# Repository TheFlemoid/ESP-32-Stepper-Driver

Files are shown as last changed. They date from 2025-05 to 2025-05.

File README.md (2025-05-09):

### ESP-WROOM-32 Based Stepper Motor Controller

PCB integrating an ESP-WROOM-32 microcontroller with two A4988/DRV8825 stepper motor drivers.

This is a four layer PCB that I originally designed this for an ESP-32 controlled, NEMA17 powered robot.  However it can also be useful for any other application requiring microcontroller control, stepper motors, and any form of SPI or I2C peripheral.

-----

Before connecting and driving the DRV8825, ensure that you set the current limit on both DRV8825/A4988 stepper drivers.

Features include:
 - 'Battery drive'.  Drive the board through a high voltage li-ion or LiPo battery, but enjoy three additional voltage rails:
    - 'Buck', aka the output from the onboard switching buck converter.
    - 5V rail through an onboard 5V LDO.
    - 3V3 rail through an onboard 3V3 LDO.
 - USB-C fast USB programming and UART.
    - USB-C programming for easy cable manipulation, but only fast USB (ie USB 2.0 speed specification) is supported.
    - 'Auto program' (utilizing USB to place the MCU in program mode) is supported.
 - Sleep, step, and direction pin connections for two DRV8825 stepper motor drivers.  Control speed, direction, and sleep on/off (useful for low current operation) for two steppers individually.
    - This was designed with the thought that each controller would be handled via the ESP-32 MCPWM peripheral, but it's entirely feasible to control them through software if desired.
 - Breakout for SPI.
 - Breakout for I2C.
    - Three pins each for both I2C SDA and SCL.
 - Voltage divider / voltmeter for 'battery' voltage.
 - Breakouts for ESP-32 GPIOs 13, 25, 26, and 36.
    - These were unused in the original design, but can be handy for extra outputs (eg another SPI CS pin) or inputs.
 - Pin headers for 1/8, 1/16, and 1/32nd microstepping.
    - Each stepper driver can be independently set for microstepping as required by your application.

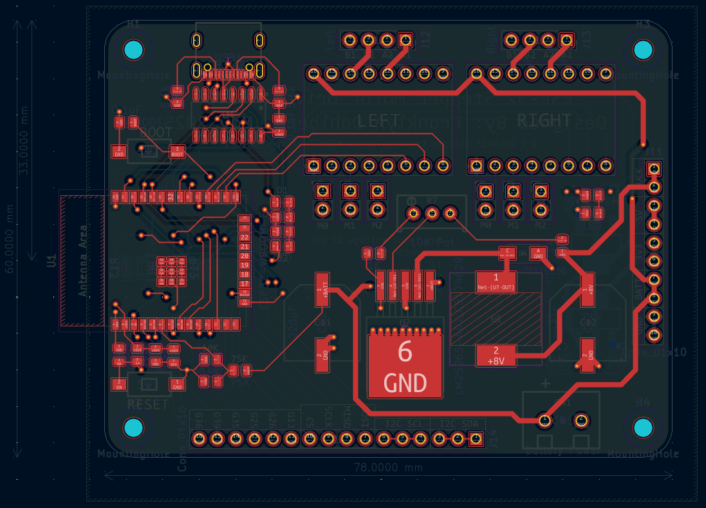
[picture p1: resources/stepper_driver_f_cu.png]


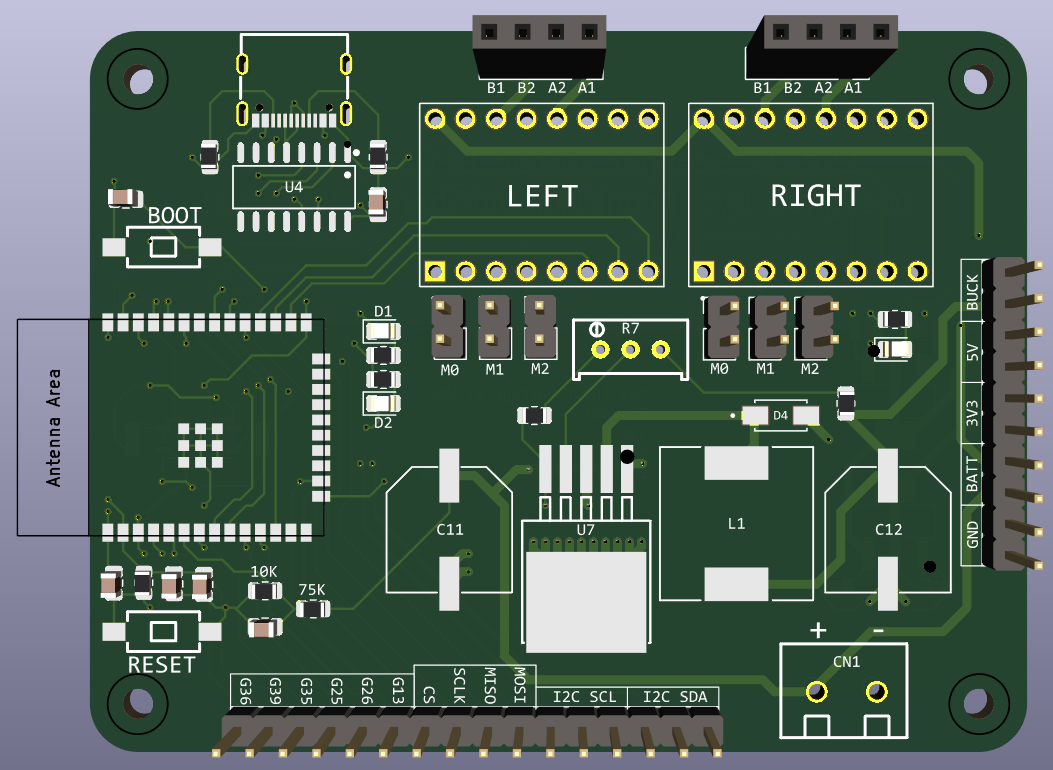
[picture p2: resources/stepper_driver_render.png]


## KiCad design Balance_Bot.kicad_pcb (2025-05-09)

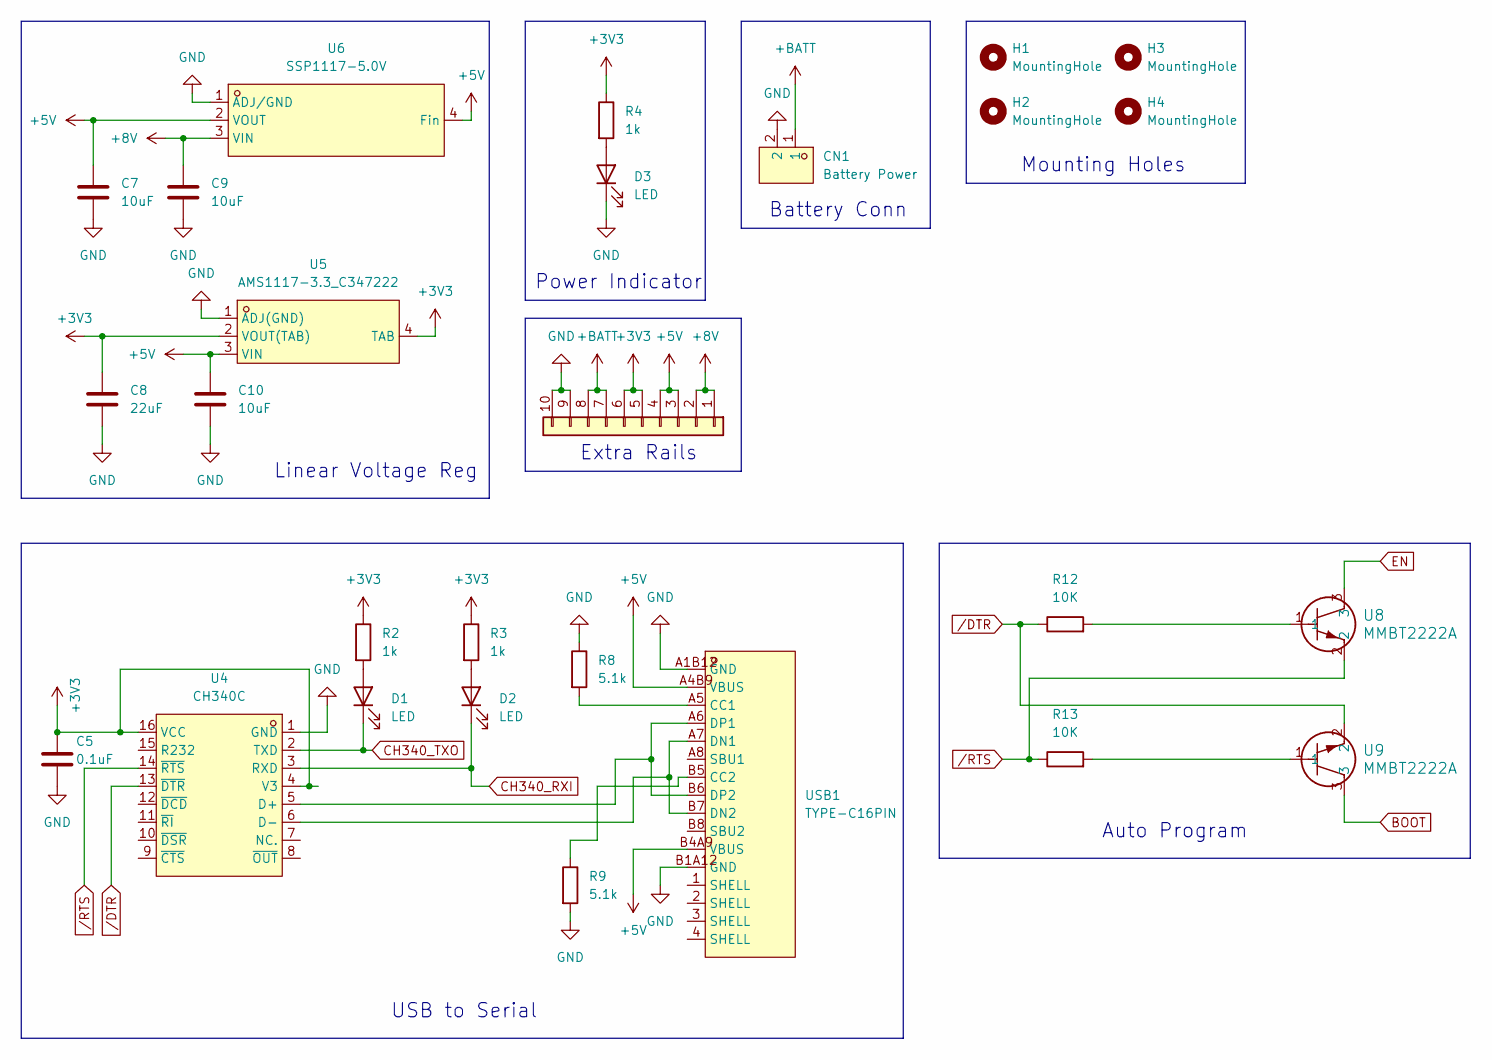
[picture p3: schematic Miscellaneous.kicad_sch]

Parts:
C5: 0.1uF; C_0805_2012Metric
C7, C9, C10: 10uF; C_0805_2012Metric
C8: 22uF; C_0805_2012Metric
CN1: Battery Power; CONN-TH_2P-P5.00_MX126-5.0-GN01-02P-CU-S-A; LCSC Part C5188434
D1, D2, D3: LED; LED_0805_2012Metric
H1, H2, H3, H4: MountingHole; MountingHole_2.5mm
J11: Conn_01x10; PinHeader_1x10_P2.54mm_Vertical
R2, R3, R4: 1k; R_0805_2012Metric
R8, R9: 5.1k; R_0805_2012Metric
R12, R13: 10K; R_0805_2012Metric
U4: CH340C; SOP-16_L10.0-W3.9-P1.27-LS6.0-BL; LCSC Part C84681
U5: AMS1117-3.3_C347222; SOT-223-4_L6.5-W3.5-P2.30-LS7.0-BR; LCSC Part C347222
U6: SSP1117-5.0V; SOT-223_L6.5-W3.5-P2.30-LS7.0-BR; LCSC Part C277893
U8, U9: MMBT2222A; SOT23_FAS
USB1: TYPE-C16PIN; USB-C-SMD_TYPE-C16PIN; LCSC Part C393939

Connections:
+3V3: C5.1, C8.1, J11.5, J11.6, R2.1, R3.1, R4.1, U4.4 (V3), U4.16 (VCC), U5.2 (VOUT(TAB)), U5.4 (TAB); also elsewhere on the board
+5V: C7.1, C10.1, J11.3, J11.4, U5.3 (VIN), U6.2 (VOUT), U6.4 (Fin), USB1.A4B9 (VBUS), USB1.B4A9 (VBUS)
+8V: C9.1, J11.1, J11.2, U6.3 (VIN); also elsewhere on the board
+BATT: CN1.1, J11.7, J11.8; also elsewhere on the board
BOOT: U9.3; also elsewhere on the board
CH340_RXI: D2.1 (K), U4.3 (RXD); also elsewhere on the board
CH340_TXO: D1.1 (K), U4.2 (TXD); also elsewhere on the board
EN: U8.3; also elsewhere on the board
GND: C5.2, C7.2, C8.2, C9.2, C10.2, CN1.2, D3.1 (K), J11.9, J11.10, R8.1, R9.2, U4.1 (GND), U5.1 (ADJ(GND)), U6.1 (ADJ/GND), USB1.A1B12 (GND), USB1.B1A12 (GND); also elsewhere on the board
unnamed: D1.2 (A), R2.2
unnamed: D2.2 (A), R3.2
unnamed: D3.2 (A), R4.2
unnamed: R12.2, U8.1
unnamed: R13.2, U9.1
unnamed: U4.5 (D+), USB1.A6 (DP1), USB1.B6 (DP2)
unnamed: U4.6 (D-), USB1.A7 (DN1), USB1.B7 (DN2)
unnamed: R8.2, USB1.A5 (CC1)
unnamed: R9.1, USB1.B5 (CC2)
/DTR: R12.1, U4.13 (~DTR), U9.2
/RTS: R13.1, U4.14 (~RTS), U8.2

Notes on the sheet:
Linear Voltage Reg
Mounting Holes
Extra Rails
USB to Serial
Power Indicator
Auto Program
Battery Conn

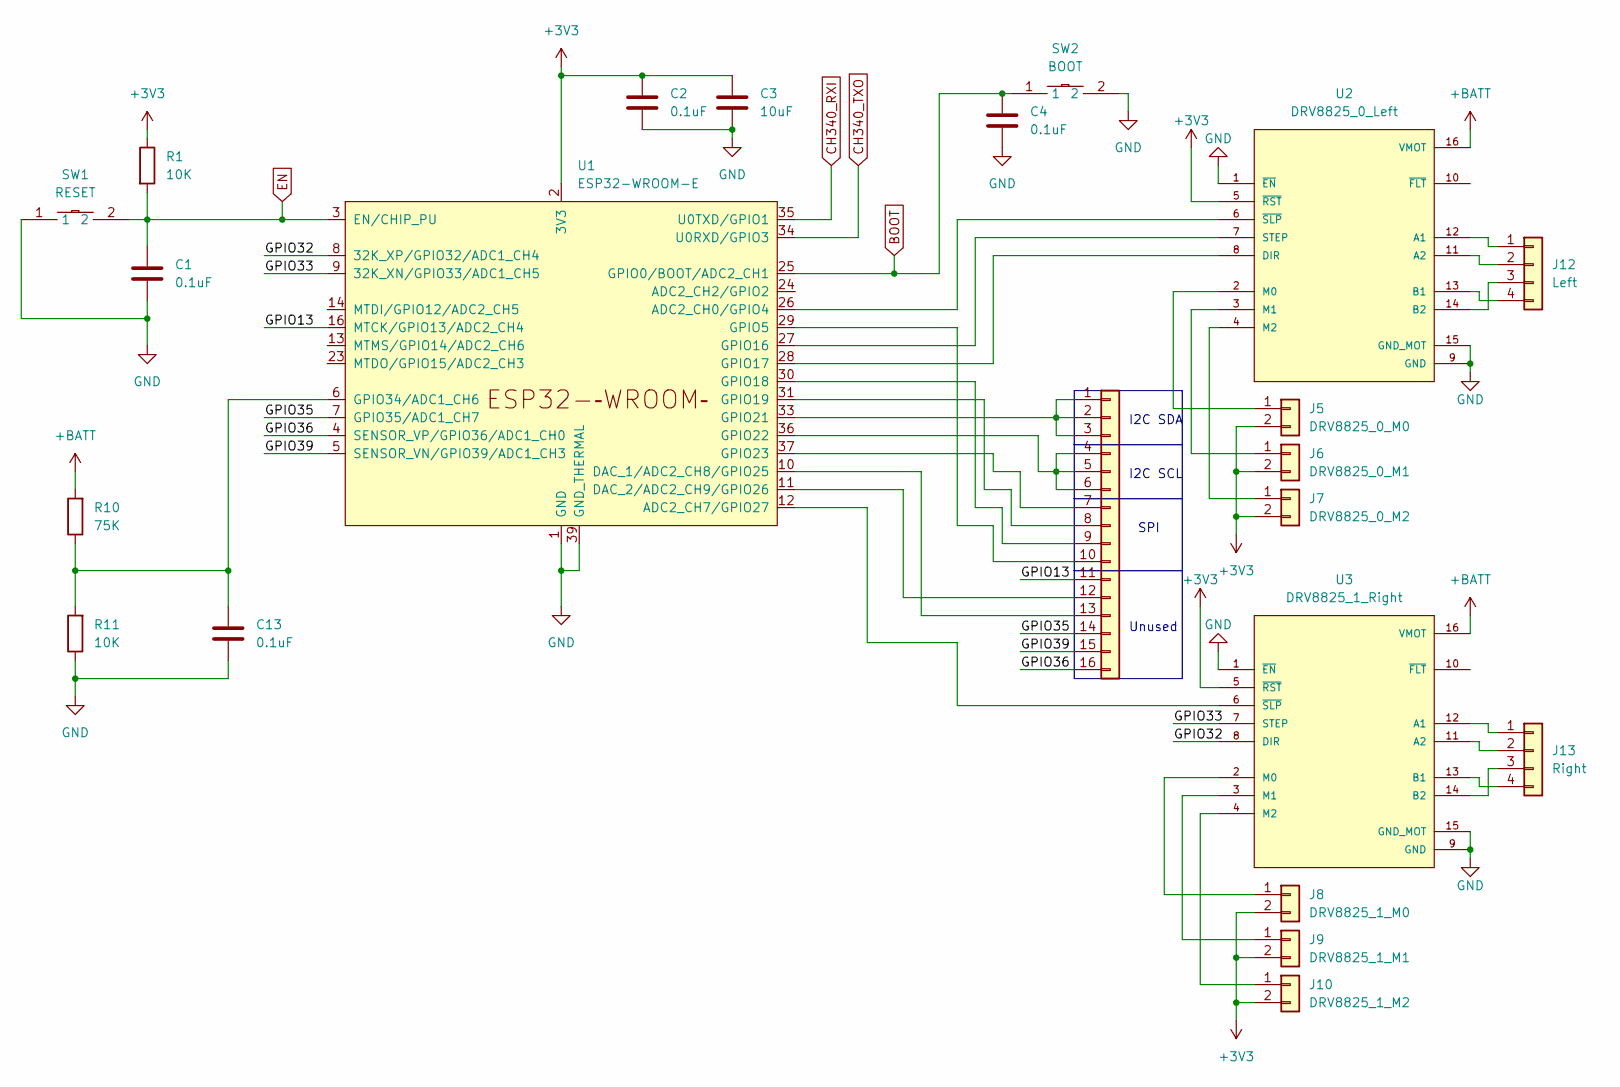
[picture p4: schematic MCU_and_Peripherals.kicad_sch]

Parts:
C1, C2, C4, C13: 0.1uF; C_0805_2012Metric
C3: 10uF; C_0805_2012Metric
J5: DRV8825_0_M0; PinHeader_1x02_P2.54mm_Vertical
J6: DRV8825_0_M1; PinHeader_1x02_P2.54mm_Vertical
J7: DRV8825_0_M2; PinHeader_1x02_P2.54mm_Vertical
J8: DRV8825_1_M0; PinHeader_1x02_P2.54mm_Vertical
J9: DRV8825_1_M1; PinHeader_1x02_P2.54mm_Vertical
J10: DRV8825_1_M2; PinHeader_1x02_P2.54mm_Vertical
J12: Left; PinSocket_1x04_P2.54mm_Vertical
J13: Right; PinSocket_1x04_P2.54mm_Vertical
J14: Conn_01x16; PinHeader_1x16_P2.54mm_Vertical
R1, R11: 10K; R_0805_2012Metric
R10: 75K; R_0805_2012Metric
SW1: RESET; SW-SMD_L6.0-W3.3-LS8.0; LCSC Part C318938
SW2: BOOT; SW-SMD_L6.0-W3.3-LS8.0; LCSC Part C318938
U1: ESP32-WROOM-E; ESP32-WROOM-32E
U2: DRV8825_0_Left; IC_DRV8825_STEPPER_MOTOR_DRIVER_CARRIER
U3: DRV8825_1_Right; IC_DRV8825_STEPPER_MOTOR_DRIVER_CARRIER

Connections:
+3V3: C2.1, C3.1, J5.2, J6.2, J7.2, J8.2, J9.2, J10.2, R1.1, U1.2 (3V3), U2.5 (~RST), U3.5 (~RST); also elsewhere on the board
+BATT: R10.2, U2.16 (VMOT), U3.16 (VMOT); also elsewhere on the board
/MCU_and_Peripherals/GPIO13: J14.11, U1.16 (MTCK/GPIO13/ADC2_CH4)
/MCU_and_Peripherals/GPIO32: U1.8 (32K_XP/GPIO32/ADC1_CH4), U3.8 (DIR)
/MCU_and_Peripherals/GPIO33: U1.9 (32K_XN/GPIO33/ADC1_CH5), U3.7 (STEP)
/MCU_and_Peripherals/GPIO35: J14.14, U1.7 (GPIO35/ADC1_CH7)
/MCU_and_Peripherals/GPIO36: J14.16, U1.4 (SENSOR_VP/GPIO36/ADC1_CH0)
/MCU_and_Peripherals/GPIO39: J14.15, U1.5 (SENSOR_VN/GPIO39/ADC1_CH3)
BOOT: C4.1, SW2.1, U1.25 (GPIO0/BOOT/ADC2_CH1); also elsewhere on the board
CH340_RXI: U1.35 (U0TXD/GPIO1); also elsewhere on the board
CH340_TXO: U1.34 (U0RXD/GPIO3); also elsewhere on the board
EN: C1.1, R1.2, SW1.2, U1.3 (EN/CHIP_PU); also elsewhere on the board
GND: C1.2, C2.2, C3.2, C4.2, C13.2, R11.1, SW1.1, SW2.2, U1.1 (GND), U1.15 (GND), U1.38 (GND), U1.39 (GND_THERMAL), U2.1 (~EN), U2.9 (GND), U2.15 (GND_MOT), U3.1 (~EN), U3.9 (GND), U3.15 (GND_MOT); also elsewhere on the board
unnamed: J5.1, U2.2 (M0)
unnamed: J6.1, U2.3 (M1)
unnamed: J7.1, U2.4 (M2)
unnamed: J8.1, U3.2 (M0)
unnamed: J9.1, U3.3 (M1)
unnamed: J10.1, U3.4 (M2)
unnamed: J12.1, U2.12 (A1)
unnamed: J12.2, U2.11 (A2)
unnamed: J12.3, U2.14 (B2)
unnamed: J12.4, U2.13 (B1)
unnamed: J13.1, U3.12 (A1)
unnamed: J13.2, U3.11 (A2)
unnamed: J13.3, U3.14 (B2)
unnamed: J13.4, U3.13 (B1)
unnamed: J14.1, J14.2, J14.3, U1.33 (GPIO21)
unnamed: J14.4, J14.5, J14.6, U1.36 (GPIO22)
unnamed: J14.7, U1.37 (GPIO23)
unnamed: J14.8, U1.31 (GPIO19)
unnamed: J14.9, U1.30 (GPIO18)
unnamed: J14.10, U1.29 (GPIO5)
unnamed: J14.12, U1.11 (DAC_2/ADC2_CH9/GPIO26)
unnamed: J14.13, U1.10 (DAC_1/ADC2_CH8/GPIO25)
unnamed: U1.26 (ADC2_CH0/GPIO4), U2.6 (~SLP)
unnamed: U1.12 (ADC2_CH7/GPIO27), U3.6 (~SLP)
unnamed: U1.27 (GPIO16), U2.7 (STEP)
unnamed: U1.28 (GPIO17), U2.8 (DIR)
unnamed: C13.1, R10.1, R11.2, U1.6 (GPIO34/ADC1_CH6)

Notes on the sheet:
I2C SDA
Unused
SPI
I2C SCL

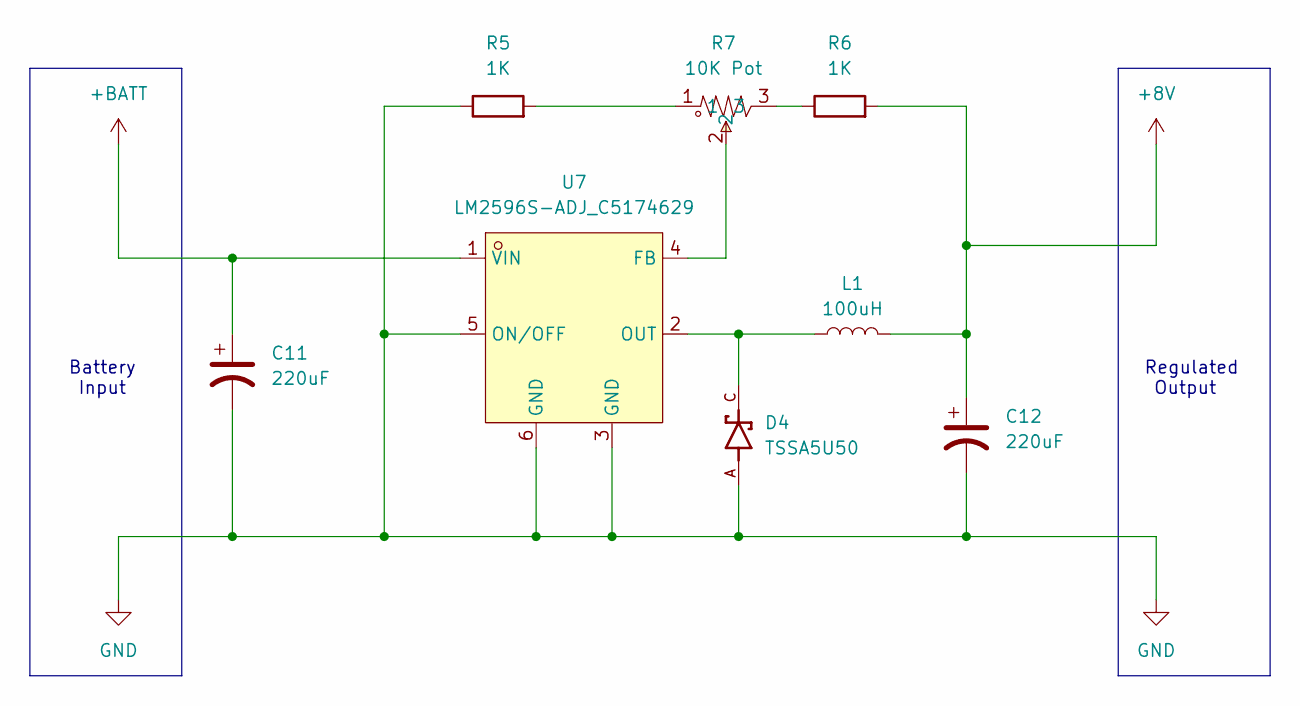
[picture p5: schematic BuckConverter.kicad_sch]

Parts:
C11, C12: 220uF; CAP-SMD_BD10.0-L10.3-W10.3-LS11.3-FD
D4: TSSA5U50; DIOM4325X250N; PARTREV O2102
L1: 100uH; IND_BOURNS_SRR1210
R5, R6: 1K; R_0805_2012Metric
R7: 10K Pot; RES-ADJ-TH_3P-L10.0-W10.0-P2.50-L; LCSC Part C118954
U7: LM2596S-ADJ_C5174629; TO-263-5_L10.0-W8.4-P1.70-LS15.3-BR; LCSC Part C5174629

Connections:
+8V: C12.1, L1.2, R6.2; also elsewhere on the board
+BATT: C11.1, U7.1 (VIN); also elsewhere on the board
GND: C11.2, C12.2, D4.A, R5.1, U7.3 (GND), U7.5 (ON/OFF), U7.6 (GND); also elsewhere on the board
unnamed: R5.2, R7.1
unnamed: R6.1, R7.3
unnamed: R7.2, U7.4 (FB)
unnamed: D4.C, L1.1, U7.2 (OUT)

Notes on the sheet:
Regulated Output
Battery Input

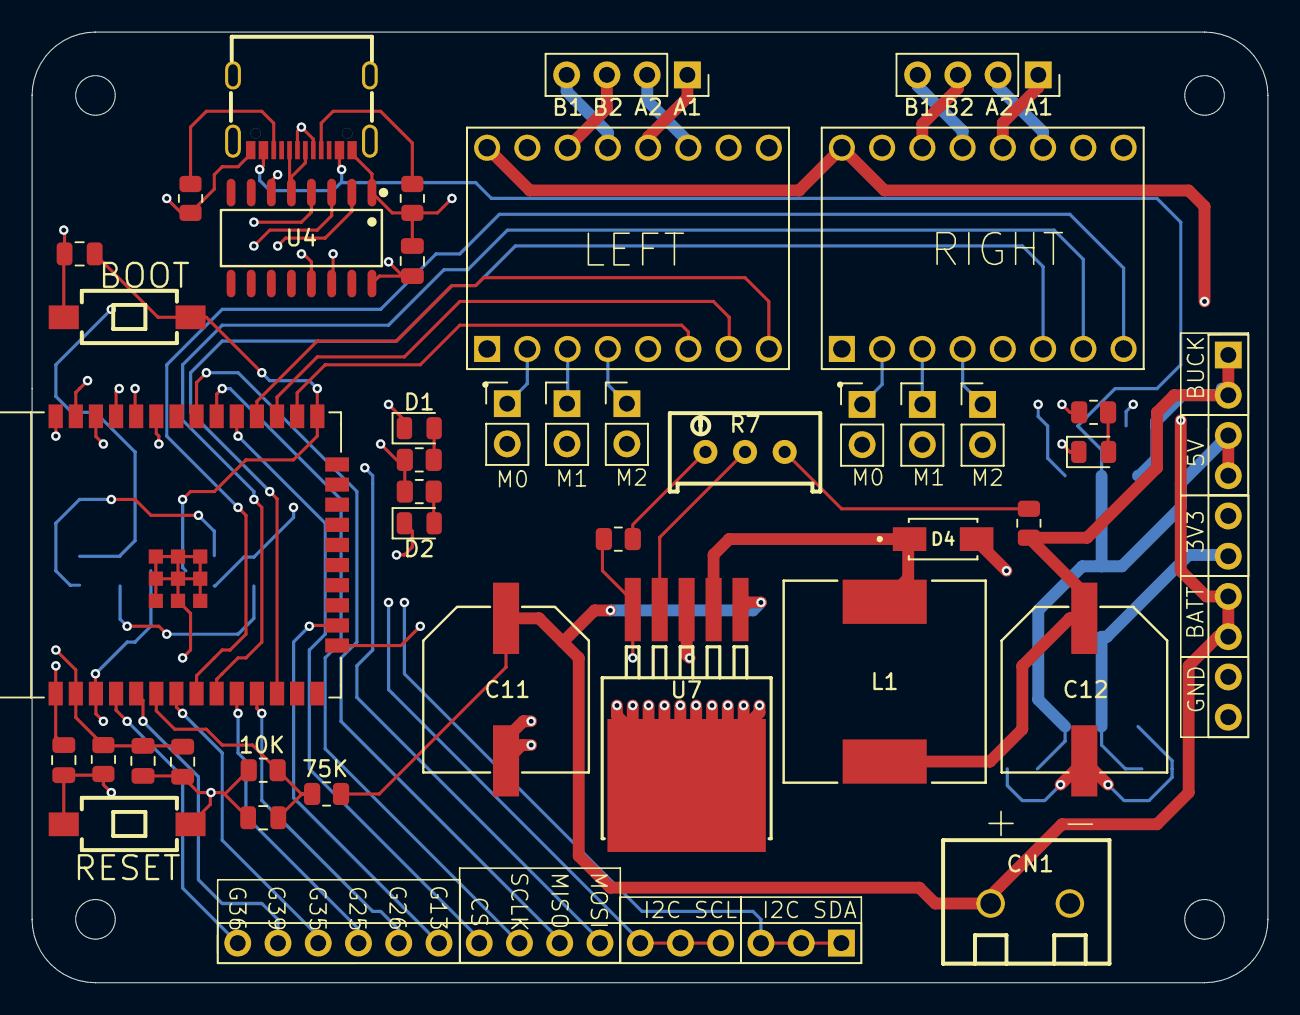
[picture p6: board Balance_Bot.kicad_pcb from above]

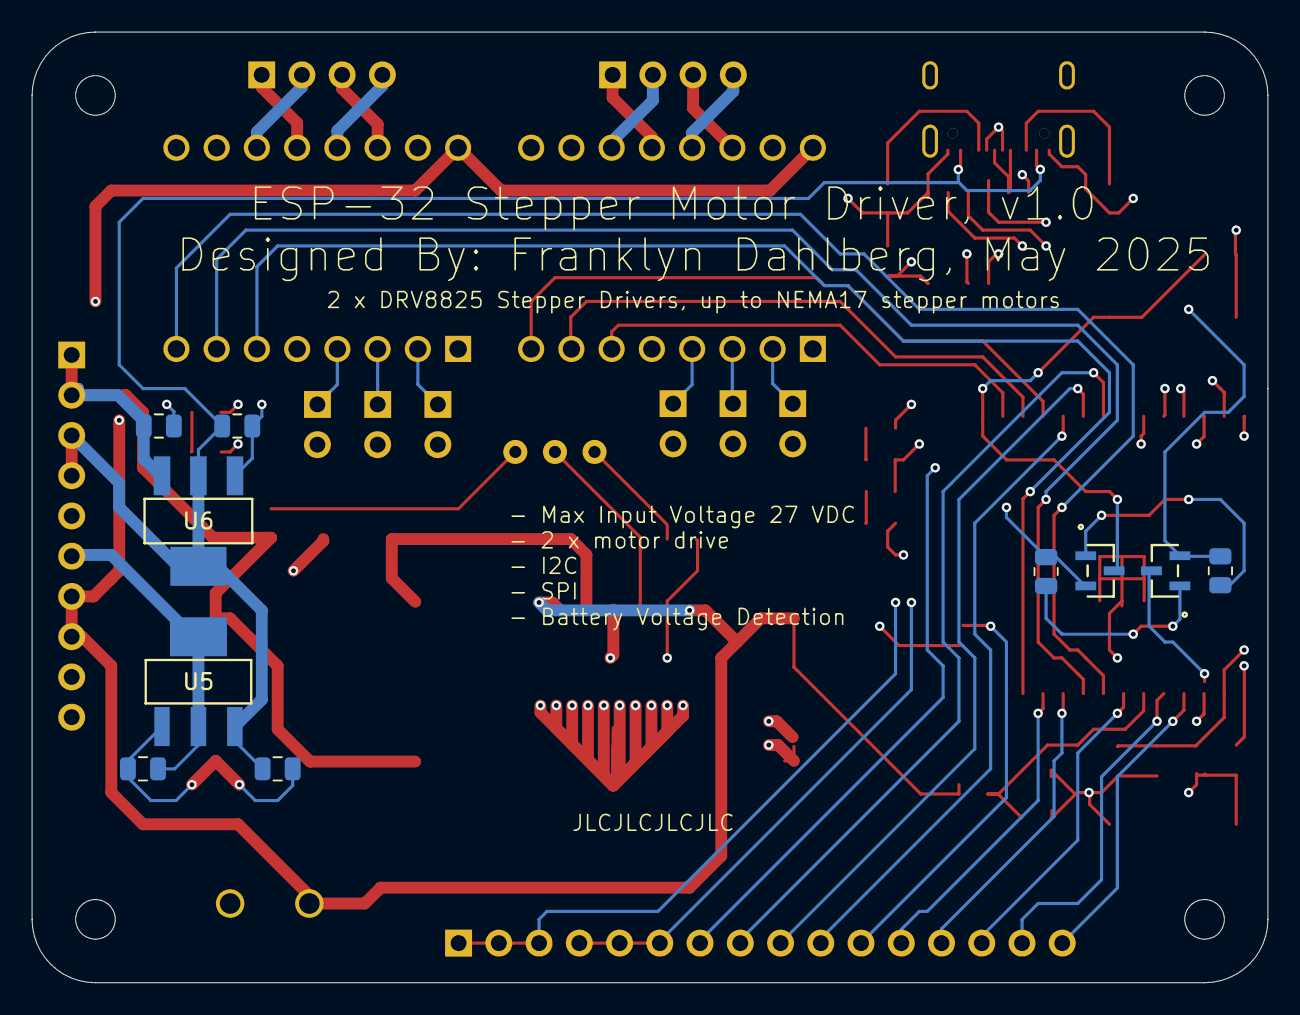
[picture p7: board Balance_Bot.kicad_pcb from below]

Board: 4 copper layers, 78.0 x 60.0 mm, 57 parts (10 on the bottom side), 57 nets.

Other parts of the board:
BOOT: BOOT; SW-SMD_L6.0-W3.3-LS8.0
RESET: RESET; SW-SMD_L6.0-W3.3-LS8.0

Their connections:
BOOT: BOOT.1; also elsewhere on the board
EN: RESET.2; also elsewhere on the board
GND: BOOT.2, RESET.1; also elsewhere on the board
